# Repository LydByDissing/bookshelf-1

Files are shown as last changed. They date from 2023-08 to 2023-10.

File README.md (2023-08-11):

Bookshelf 1 a Lyd by Dissing project

# Bookshelf 1

This is a simply bookshelf speaker, based on a COAX driver from SB Acoustics. The cabinet are a bass reflex cabinet to increase the bass response.

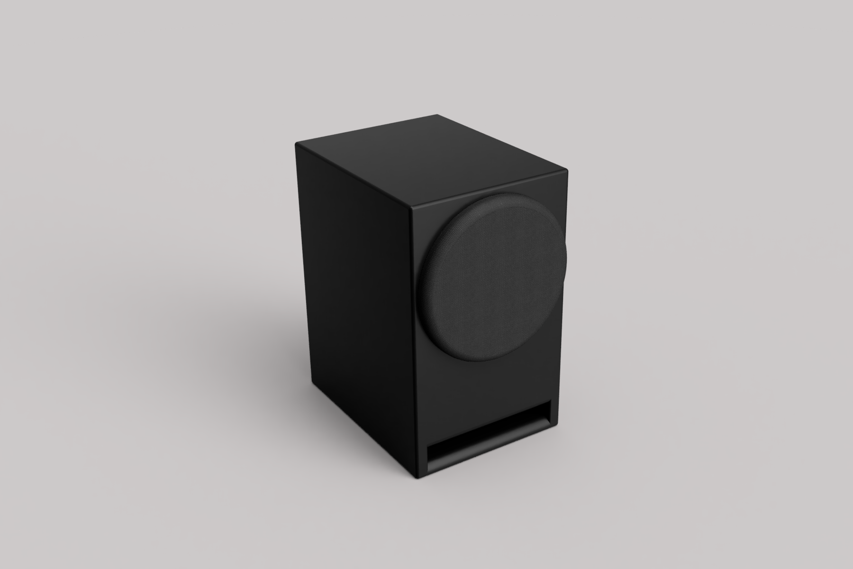
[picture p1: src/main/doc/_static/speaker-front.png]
Bookshelf 1 front view


## License
This project and all it's work are licensed under the [CERN Open Hardware Licence Version 2](https://ohwr.org/project/cernohl/wikis/Documents/CERN-OHL-version-2) license.

## Design goals

Initial design goals for this bookshelf speaker:

* Use a COAX driver for optimal timing between drivers
* Compact cabinet
* In room bass extention into the 40Hz range

## Current progress

Prototype cabinet have been designed and built. Initial measurements are been captured. Find them under the [measurements](measurements) folder.

Working on the finishing of the cabinet. Going with a painted finish and initially no driver cover.

An initial crossover have been designed, based on the captured measurements. I'm going for a 2nd order series filter. Currently it looks as depicted below.
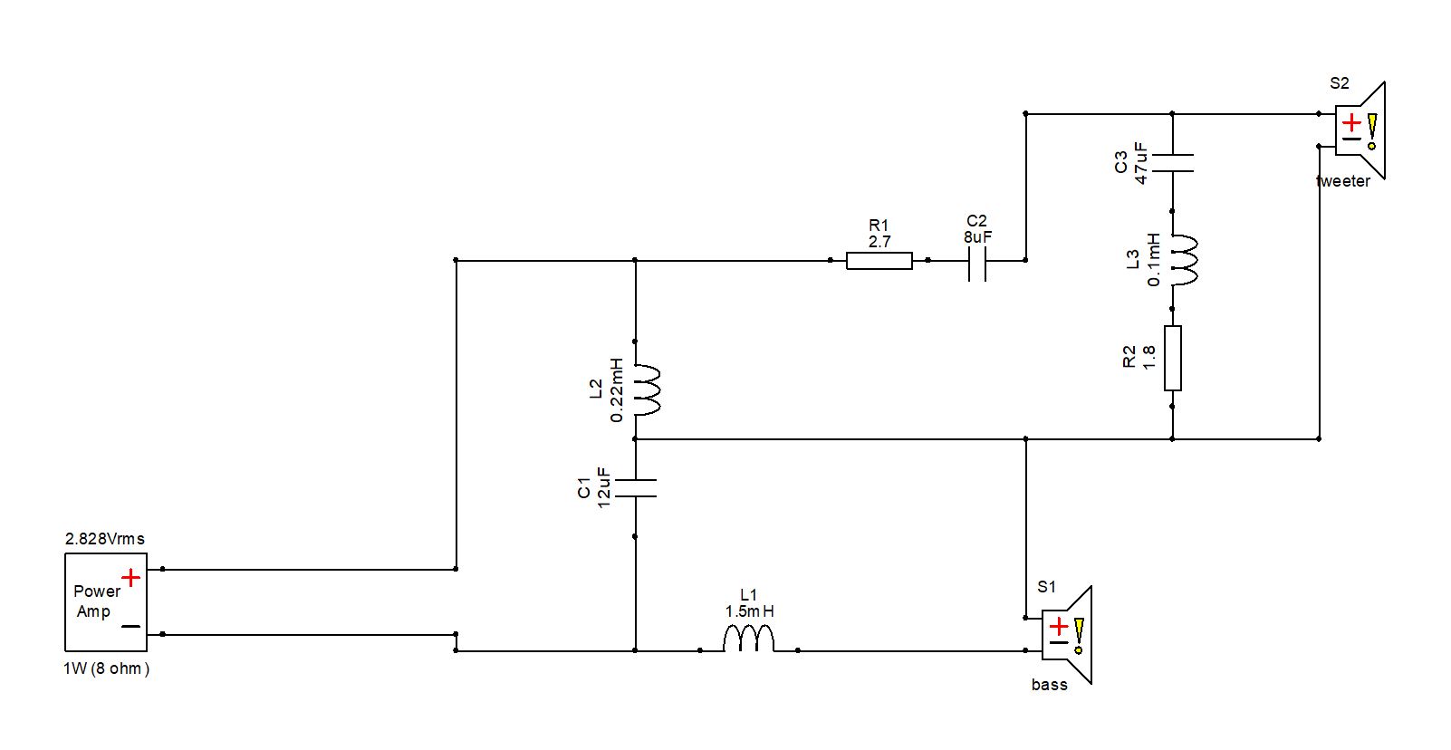
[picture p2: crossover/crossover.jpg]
2nd order series crossover filter


The currently simulated results of the speaker + filter looks like this. This result will need to be confirmed by a measurement once the components have arrived.

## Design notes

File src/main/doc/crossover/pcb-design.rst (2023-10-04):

PCB Design of the crossover
###########################

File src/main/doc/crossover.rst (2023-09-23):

Speaker crossover
#################

The crossover have been simulated and modelled in XSim. The crossover file linked below contains the filter simulation.
The measurements used doesn't include impendance measurements.

We are going for a crossover frequence of around 2500Hz. This to keep a reasonable wide dispersion for the entire frequency range.

As seen in the driver measurements (can be downloaded below) the bass driver has various issues above the crossover frequency wich require us to ensure that these are lowered enough, to not make an audible impact in the tweeter section.

.. toctree::
  :caption: Documentation Sections
  :maxdepth: 1

  crossover/pcb-design.rst

Crossover layout
================

The crossover is a 2-way series and is of 2nd order.

2nd order crossover

Simulated result
==========================

The above crossover have been simulated and constructed in XSim. With the above values the simulation results in the below frequency response:

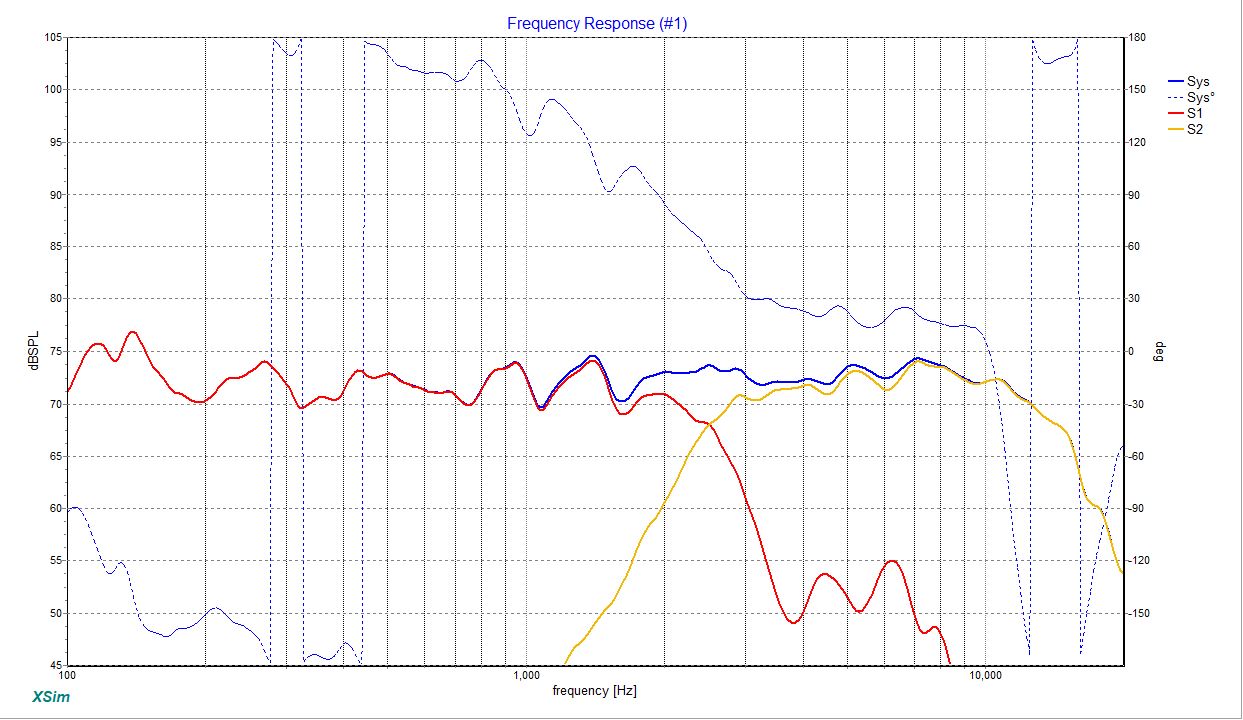
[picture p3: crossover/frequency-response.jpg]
Frequency response


Measured result
===============

This is the resulting measurement after I have fittet the crossover (version 2).

.. chart:: measurements/crossover-v2.json

    Measured frequency response of an initial test cabinet and test crossover (v2). As this is an in room measurement, the bass section and phase result can't be expected to be 100% correct.

Downloads
=========

* Download the XSim crossover design in .DXO format :download:`2-way_LR_eries.dxo <../../../crossover/2-way_LR_eries.dxo>`.
* Download the measurements for the bass driver in .MDAT (Room EQ Wizard) format :download:`bass baseline.mdat <../../../measurements/20230805/bass baseline 71.mdat>`.
* Download the measurements for the tweeter in .MDAT (Room EQ Wizard) format :download:`tweeter baseline.mdat <../../../measurements/20230805/tweeter baseline 72.mdat>`.

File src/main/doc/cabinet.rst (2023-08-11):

Cabient design
##############

The speaker cabinet are designed as a bass reflex design, to try to increase the bass extension. As this is a fairly small form factor, the port has to be rather long.

Cabinet design
==============

We are going for a small box with this project. It is a bookshelf speaker after all. Around 6l of internal cabient volume.
It will be built of 12mm MDF or similar material.

The baffle will be constructed as a sandwich of two layers. So 24mm in thickness.

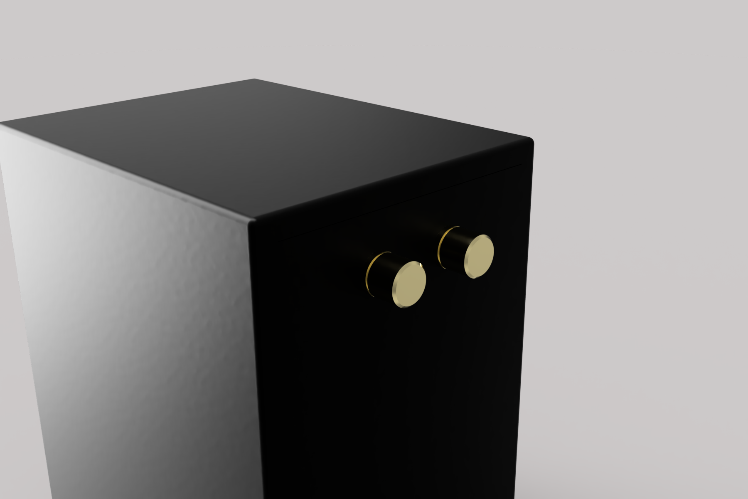
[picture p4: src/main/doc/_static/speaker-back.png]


We have used an open source project called `SpeakerSim <https://lightbit.gitlab.io/file/>`_ for the simulations. The project file can be downloaded below.

The simulation looks like this, giving us a -6dB output level at the port tuning frequency.

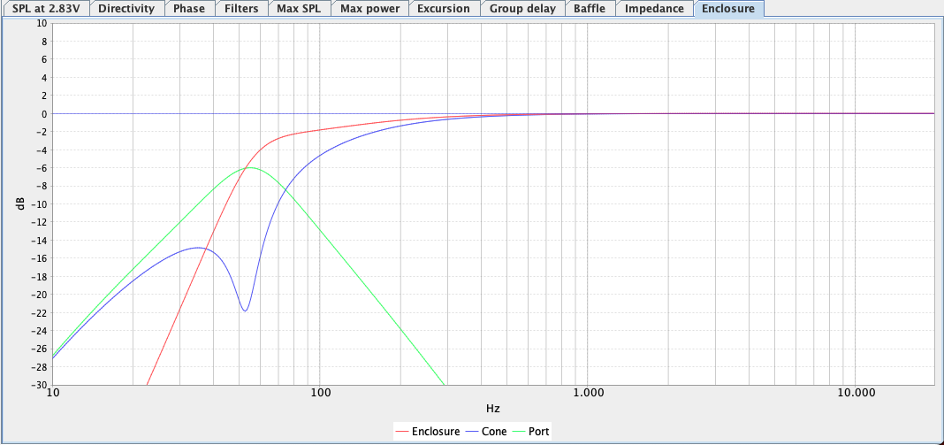
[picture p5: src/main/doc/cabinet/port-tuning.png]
Tuning of the reflex port and box


Port design
===========

With this port we are trying to tune it as low as the box will allow us. As seen above this gets us to around 53Hz. This tuning frequency requires a rather long port, as this is a small box.

The port is a slot type port and to make it fit inside the cabinet it needs to have a bend; more or less in the middle. The result are a port slot with a lenght of about 25cm. A port that almost travels the entire buttom and back of the inside of the cabinet.

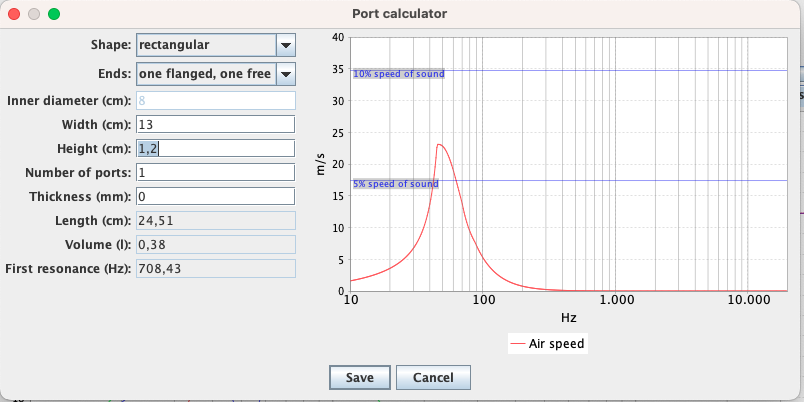
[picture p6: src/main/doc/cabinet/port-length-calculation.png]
Reflex port length calculation


To make the port fit inside the cabinet -- and avoiding a second bend -- it also have to be rather narrow (a larger diameter will require an even longer port). This increases the air velocity in the port at high output levels, which will result in port noises.
We are trying to mitigate/limit these effects by adding a flare to each end of the port slot.

Downloads
=========

* Download the SpeakerSim project in .ssim format :download:`bookshelf.ssim <../../../bookshelf.ssim>`.

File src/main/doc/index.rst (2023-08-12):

.. Bookshelf 1 documentation master file, created by
   sphinx-quickstart on Tue Aug  8 17:27:13 2023.
   You can adapt this file completely to your liking, but it should at least
   contain the root `toctree` directive.

###########
Bookshelf 1
###########

This is a simply bookshelf speaker, based on a COAX driver from SB Acoustics.
The cabinet are a bass reflex design; which helps to increase the bass response.



.. toctree::
  :caption: Documentation Sections
  :maxdepth: 1

  cabinet
  crossover
  contributing
  license
  changelog

.. Indices and tables
   ==================

   * :ref:`genindex`
   * :ref:`modindex`
   * :ref:`search`

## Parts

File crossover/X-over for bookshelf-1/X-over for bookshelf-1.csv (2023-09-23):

# | Reference | Qty | Value | Footprint | DNP
1 | C1 | 1 | 12µF | Capacitor_THT:CP_Axial_L42.5mm_D20.0mm_P49.00mm_Horizontal
2 | C2 | 1 | 47µF | Capacitor_THT:CP_Axial_L55.0mm_D35.0mm_P60.00mm_Horizontal
3 | C3 | 1 | 8µF | Capacitor_THT:CP_Axial_L42.5mm_D20.0mm_P49.00mm_Horizontal
4 | J1 | 1 | Screw_Terminal_01x02 | Connector_Wire:SolderWire-0.5sqmm_1x02_P4.6mm_D0.9mm_OD2.1mm
5 | J2 | 1 | Screw_Terminal_01x04 | Connector_Wire:SolderWire-0.5sqmm_1x04_P4.6mm_D0.9mm_OD2.1mm
6 | L1 | 1 | 1,5mH | Inductor_THT:L_Radial_D24.4mm_P23.90mm_Murata_1400series
7 | L2 | 1 | 0,22mH | Inductor_THT:L_Radial_D40.6mm_P26.16mm_Vishay_IHB-5
8 | L3 | 1 | 0,1mH | Inductor_THT:L_Radial_D50.8mm_P33.27mm_Vishay_IHB-6
9 | R1 | 1 | 1,8Ω | Resistor_THT:R_Axial_Power_L48.0mm_W12.5mm_P60.96mm
10 | R2 | 1 | 2,7Ω | Resistor_THT:R_Axial_Power_L48.0mm_W12.5mm_P60.96mm

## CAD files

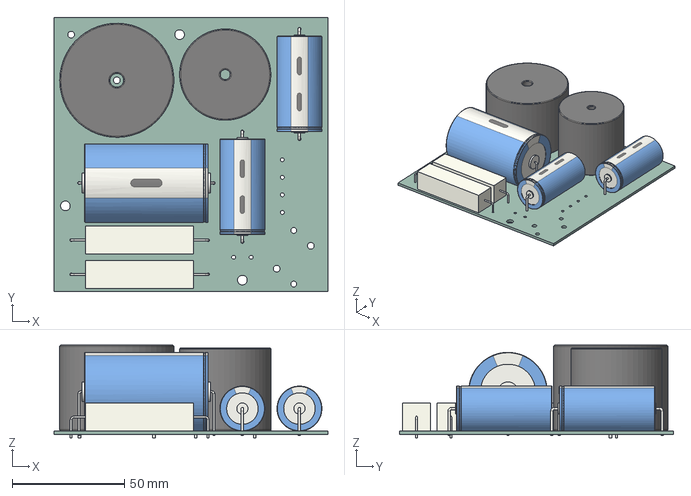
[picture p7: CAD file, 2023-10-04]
crossover/X-over for bookshelf-1/X-over for bookshelf-1.step
121.9 x 121.9 x 41.2 mm
X-over for bookshelf-1 PCB

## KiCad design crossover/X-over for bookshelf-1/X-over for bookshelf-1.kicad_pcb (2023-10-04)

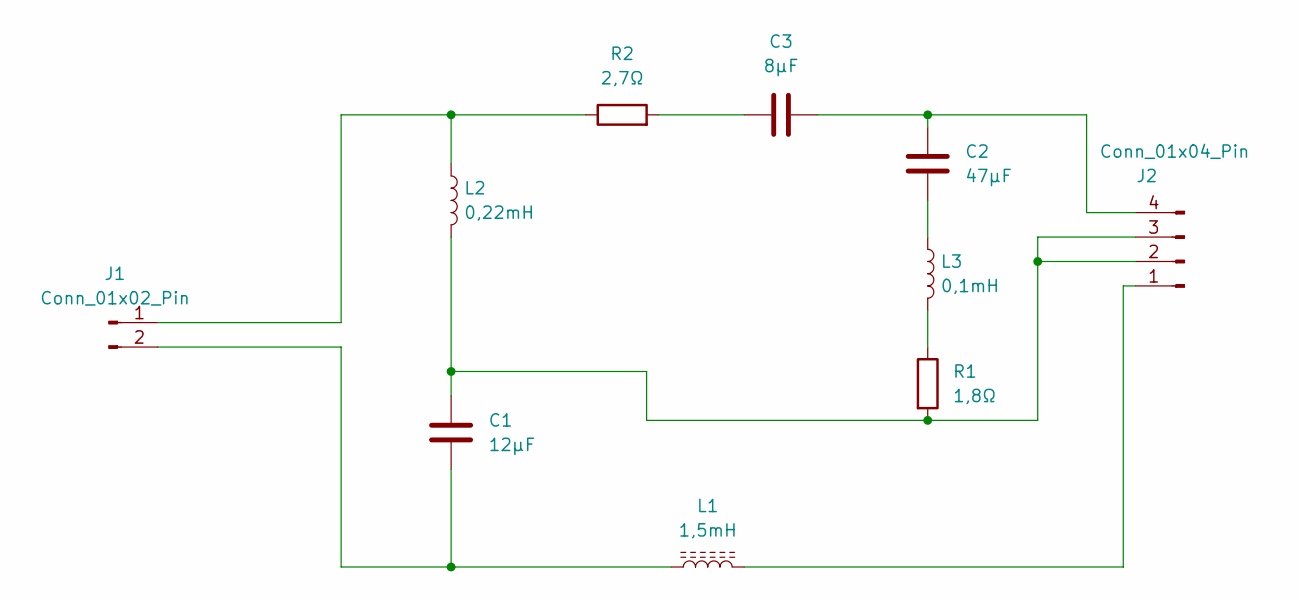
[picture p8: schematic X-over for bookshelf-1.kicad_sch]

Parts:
C1: 12µF; CP_Axial_L42.5mm_D20.0mm_P49.00mm_Horizontal
C2: 47µF; CP_Axial_L55.0mm_D35.0mm_P60.00mm_Horizontal
C3: 8µF; CP_Axial_L42.5mm_D20.0mm_P49.00mm_Horizontal
J1: Conn_01x02_Pin; SolderWire-1sqmm_1x02_P7.8mm_D1.4mm_OD3.9mm
J2: Conn_01x04_Pin; SolderWire-1sqmm_1x04_P7.8mm_D1.4mm_OD3.9mm
L1: 1,5mH; L_Radial_D24.4mm_P23.90mm_Murata_1400series
L2: 0,22mH; L_Radial_D40.6mm_P26.16mm_Vishay_IHB-5
L3: 0,1mH; L_Radial_D50.8mm_P33.27mm_Vishay_IHB-6
R1: 1,8Ω; R_Axial_Power_L48.0mm_W12.5mm_P60.96mm
R2: 2,7Ω; R_Axial_Power_L48.0mm_W12.5mm_P60.96mm

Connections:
unnamed: C2.2, L3.1
unnamed: C3.1, R2.2
unnamed: J1.1, L2.1, R2.1
unnamed: C1.2, J1.2, L1.1
unnamed: J2.1, L1.2
unnamed: C1.1, J2.2, J2.3, L2.2, R1.2
unnamed: C2.1, C3.2, J2.4
unnamed: L3.2, R1.1

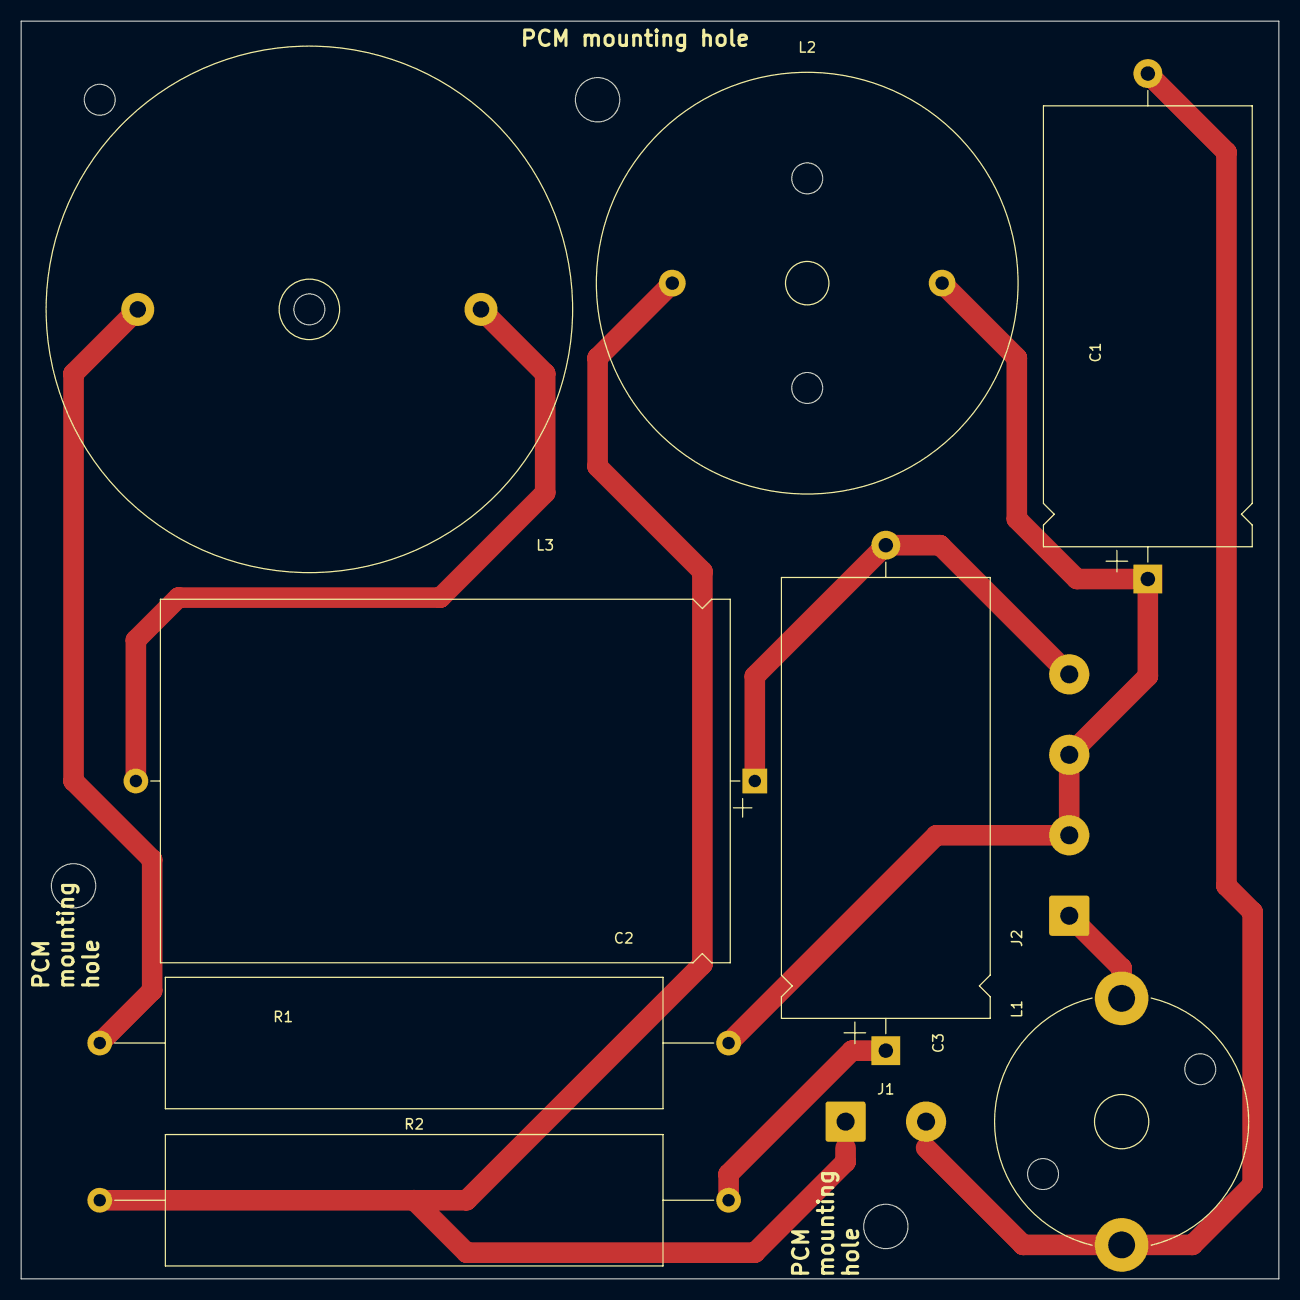
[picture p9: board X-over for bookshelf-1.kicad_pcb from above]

Board: 2 copper layers, 121.9 x 121.9 mm, 10 parts (0 on the bottom side), 8 nets.

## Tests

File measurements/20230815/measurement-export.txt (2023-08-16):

* Measurement data measured by REW V5.20.13
* Source: Umik-1  Gain: 12dB  , MICROPHONE, R, volume: 1.000. Timing signal peak level -23.0 dBFS, measurement signal peak level -18.0 dBFS
* Format: 512k Log Swept Sine, 1 sweep at -12.0 dBFS using an acoustic timing reference
* Dated: Aug 15, 2023 8:38:56 PM
* REW Settings:
*  C-weighting compensation: Off
*  Target level: 75.0 dB
* Note: Delay -0.1348 ms (-46 mm, -1.82 in) using IR start time relative to Acoustic reference played from SPEAKER R with -0.0186 ms (-6.4 mm, -0.25 in) timing offset Clock adjustment: 1,237.9 ppm
* Measurement: crossover v2 76
* Smoothing: Psychoacoustic
* Frequency Step: 1/48 octave
* Start Frequency: 20.300 Hz
*
* Freq(Hz), SPL(dB), Phase(degrees)
20.299999, 55.906, 39.9091
20.600000, 56.535, 39.5339
20.900000, 57.166, 39.1173
21.200001, 57.791, 38.6109
21.400000, 58.202, 38.2065
21.799999, 59.005, 37.2004
22.000000, 59.396, 36.5762
22.400000, 60.152, 35.0373
22.700001, 60.695, 33.5908
23.000000, 61.216, 31.8594
23.299999, 61.716, 29.8183
23.600000, 62.193, 27.4493
24.000000, 62.794, 23.7593
24.299999, 63.218, 20.5851
24.700001, 63.747, 15.8124
25.000000, 64.118, 11.8380
25.400000, 64.577, 6.0372
25.799999, 64.996, -0.2945
26.200001, 65.376, -7.1007
26.500000, 65.636, -12.4766
26.900000, 65.950, -19.9528
27.200001, 66.161, -25.7492
27.600000, 66.411, -33.6725
28.000000, 66.625, -41.7503
28.500000, 66.846, -51.9571
29.000000, 67.015, -62.1618
29.500000, 67.135, -72.2515
30.000000, 67.210, -82.1193
30.400000, 67.237, -89.7931
30.700001, 67.241, -95.3948
31.100000, 67.223, -102.6303
31.500000, 67.182, -109.5743
32.000000, 67.099, -117.8109
32.500000, 66.984, -125.5261
33.000000, 66.840, -132.6995
33.500000, 66.670, -139.3223
34.000000, 66.477, -145.3940
34.500000, 66.264, -150.9217
35.000000, 66.033, -155.9180
35.500000, 65.786, -160.4020
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

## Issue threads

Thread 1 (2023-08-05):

Improve on filter design

TooDissing, 2023-08-05:
# Description

The initial filter design is a 2nd order two way series filter, as depicted here:
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

The filter started as a Linkwitz Riley filter, but all values have been adapted to make the drivers merge better.
In order to make the two drivers level match, a resistor and a notch filter on the tweeter seems to be needed, but it would be great if this could be avoided. At least to some extend.

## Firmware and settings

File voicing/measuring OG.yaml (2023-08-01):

---
devices:
  samplerate: 44100
  chunksize: 8192
  capture:
    type: CoreAudio
    channels: 2
    device: "BlackHole 2ch"
    format: FLOAT32LE
  playback:
    type: CoreAudio
    channels: 2
    device: "Built-in Output"
    #format: FLOAT32LE
    format: S16LE

mixers:
  mono:
    channels:
      in: 2
      out: 2
    mapping:
      - dest: 0
        sources:
          - channel: 0
            gain: -6
            inverted: false
          - channel: 1
            gain: -6
            inverted: false
      - dest: 1
        sources:
          - channel: 0
            gain: -6
            inverted: false
          - channel: 1
            gain: -6
            inverted: false

filters:
  LR_bass_protection:
    type: BiquadCombo
    parameters:
      type: LinkwitzRileyHighpass
      freq: 45
      order: 8
  LR_highpass_tweeter:
    type: BiquadCombo
    parameters:
      type: LinkwitzRileyHighpass
      freq: 2200
      order: 2
  LR_lowpass_bass_1:
    type: BiquadCombo
    parameters:
      type: LinkwitzRileyLowpass
      freq: 3500
      order: 2
#  LR_lowpass_bass_2:
#    type: BiquadCombo
#    parameters:
#      type: LinkwitzRileyLowpass
#      freq: 4000
#      order: 2
  hf_notch_woofer:
    type: Biquad
    parameters:
      type: Notch
      freq: 5200
      gain: -6
      bandwidth: 4
  LS_bass_boost:
    type: Biquad
    parameters:
      type: Lowshelf
      freq: 150
      gain: 6.0
      slope: 4
  tweeter_gain:
    type: Gain
    parameters:
      gain: -1
      inverted: false
      mute: false
      
pipeline:
  - type: Mixer
    name: mono
  - type: Filter
    channel: 0
    names:
      - LR_lowpass_bass_1
      - hf_notch_woofer
      #- LS_bass_boost
      - LR_bass_protection
  - type: Filter
    channel: 1
    names:
      - tweeter_gain
      - LR_highpass_tweeter
  

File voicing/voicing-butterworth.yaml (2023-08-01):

---
devices:
  samplerate: 44100
  chunksize: 8192
  capture:
    type: CoreAudio
    channels: 2
    device: "BlackHole 2ch"
    format: FLOAT32LE
  playback:
    type: CoreAudio
    channels: 2
    device: "Built-in Output"
    #format: FLOAT32LE
    format: S16LE

mixers:
  mono:
    channels:
      in: 2
      out: 2
    mapping:
      - dest: 0
        sources:
          - channel: 0
            gain: -9
            inverted: false
          - channel: 1
            gain: -9
            inverted: false
      - dest: 1
        sources:
          - channel: 0
            gain: -9
            inverted: false
          - channel: 1
            gain: -9
            inverted: false

filters:
  LR_bass_protection:
    type: BiquadCombo
    parameters:
      type: ButterworthHighpass
      freq: 45
      order: 8
  LR_highpass_tweeter:
    type: BiquadCombo
    parameters:
      type: ButterworthHighpass
      freq: 2500
      order: 2
  LR_lowpass_bass:
    type: BiquadCombo
    parameters:
      type: ButterworthLowpass
      freq: 2500
      order: 2
  LS_bass_boost:
    type: Biquad
    parameters:
      type: Lowshelf
      freq: 150
      gain: 6.0
      slope: 6
  tweeter_gain:
    type: Gain
    parameters:
      gain: -2.5
      inverted: false
      mute: false
      
pipeline:
  - type: Mixer
    name: mono
  - type: Filter
    channel: 0
    names:
#      - LS_bass_boost
#      - LR_bass_protection
      - LR_lowpass_bass
  - type: Filter
    channel: 1
    names:
      - tweeter_gain
      - LR_highpass_tweeter
  
      
  

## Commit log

2023-08-16 updating doc
    [measurement-export.csv]
2023-08-29 adding x-over KiCAD project for the crossover schematic and PCB design; at least the initial version
    [X-over for bookshelf-1.kicad_pcb, X-over for bookshelf-1.kicad_sch]
2023-08-31 adding KiCAD documents for the XO design
    [X-over for bookshelf-1.kicad_pcb]
2023-09-23 Feature/pcb updates (#3)
    * adding intial work to support PCB draw
    * Minimizing overall PCB size
    Now it should both fit inside the cabinet as well as through the driver opening.
    [X-over for bookshelf-1.csv, X-over for bookshelf-1.kicad_pcb, X-over for bookshelf-1.kicad_sch]
2023-09-24 Removing all from the failed attempt to add PCB Draw
2023-10-04 adding holes
    [X-over for bookshelf-1.kicad_pcb, X-over for bookshelf-1.kicad_sch, X-over for bookshelf-1.step]
